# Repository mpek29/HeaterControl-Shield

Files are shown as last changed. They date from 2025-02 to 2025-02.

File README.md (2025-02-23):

# HeaterControl-Shield

## 🚀 Overview
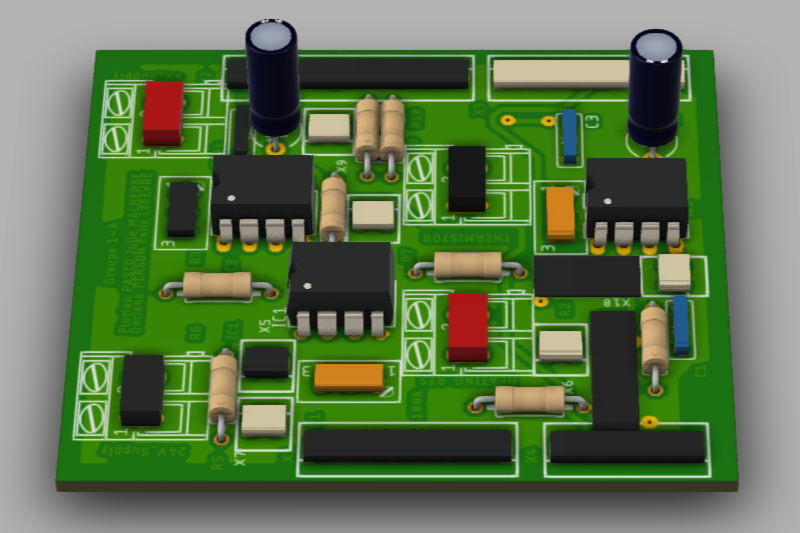
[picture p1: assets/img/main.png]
Main Preview


**HeaterControl-Shield** is an open-source electronic board designed to control a **heating resistor**, measure the **consumed current**, and detect the **temperature** near the heating resistor. This board is shaped as an **Arduino shield** and optimized for use with an **STM32 Nucleo**.

## 🎯 Main Features
- 🔥 **Heating resistor control** via an **N-channel MOSFET**.
- ⚡ **Current consumption measurement** using a **shunt resistor** and an **operational amplifier**.
- 🌡️ **Temperature sensing** using a **thermistor** integrated into a **Wheatstone bridge**, amplified by an **instrumentation amplifier**.
- 🛠️ **Open-source and customizable design** to adapt to specific project needs.

## 📝 Technical Specifications
| 🏷️ Feature | 🔍 Description |
|---|---|
| 🔌 **Power Input** | 5V - 12V |
| 🔥 **Heating Control** | N-channel MOSFET for power control |
| ⚡ **Current Measurement** | Shunt resistor + Operational amplifier |
| 🌡️ **Temperature Sensing** | Wheatstone bridge + Instrumentation amplifier |
| 🔄 **Interface** | Compatible with **Arduino Shield** and **STM32 Nucleo** |
| 🖥️ **PCB Design** | Open-source & customizable |
| 🌍 **Applications** | Thermal control projects, embedded systems, temperature regulation |

## 📐 PCB Preview
| 📜 Schematic | 🖥️ PCB Layout | 🏗️ 3D View |
|---|---|---|
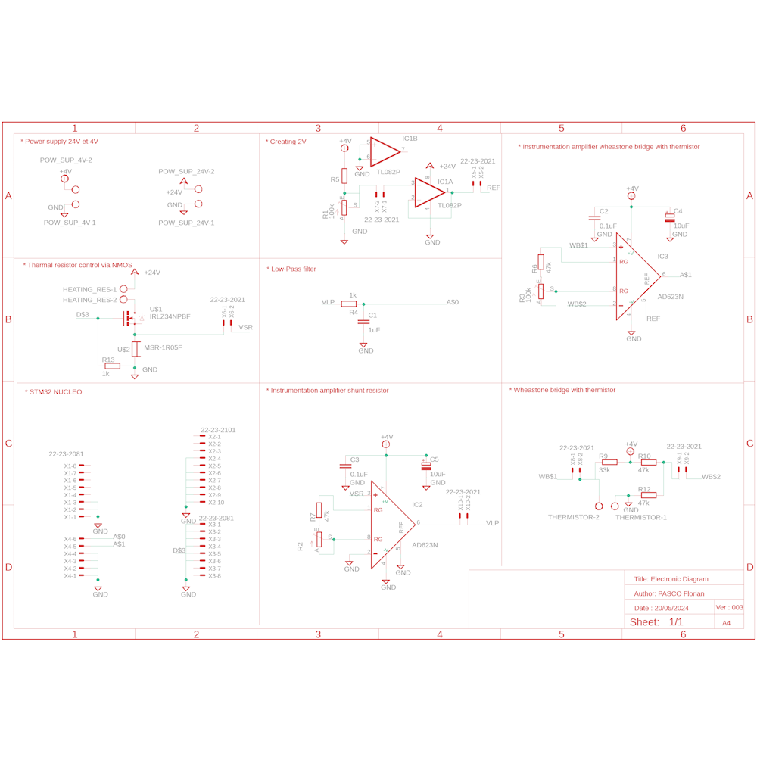
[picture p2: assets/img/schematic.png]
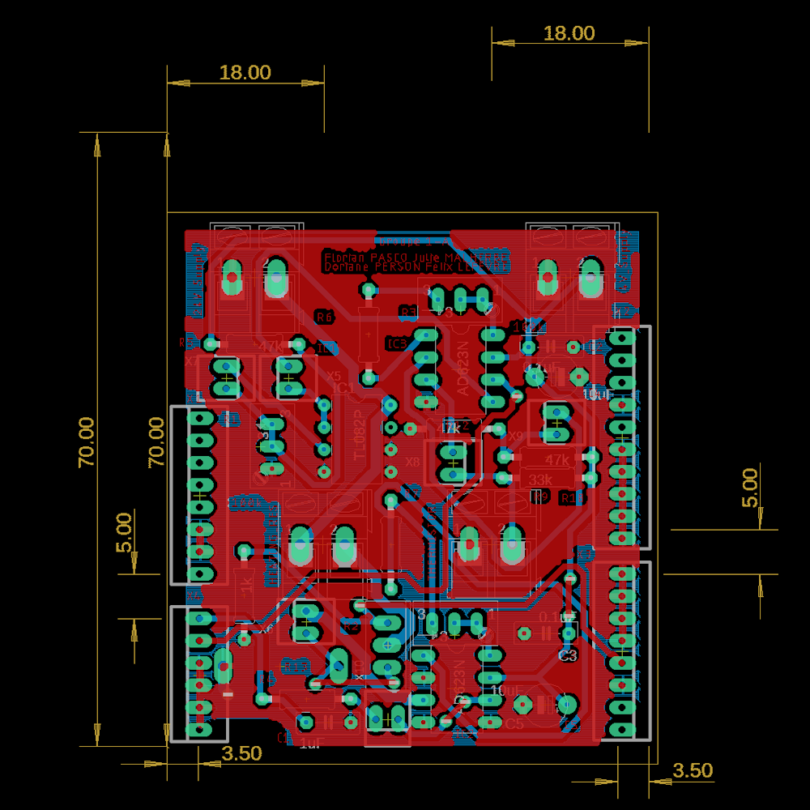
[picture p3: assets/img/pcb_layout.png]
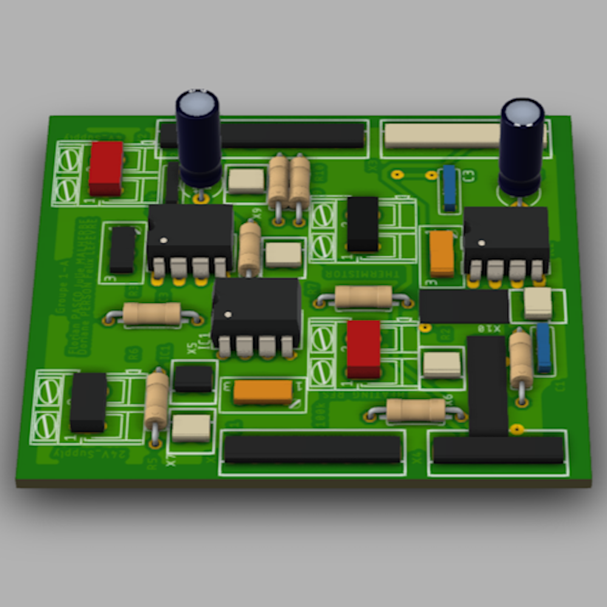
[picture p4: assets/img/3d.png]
|  |  |  |

## 🔗 Main Connections
| Pin | Function |
|-----|---|
| VIN | Main power input |
| GND | Ground |
| HEAT_CTRL | PWM signal to activate heating |
| CURR_SENSE | Amplified output of current measurement |
| TEMP_SENSE | Amplified output of temperature measurement |

## 🌟 License
This project is open-source. Feel free to use, modify, and contribute! 🚀

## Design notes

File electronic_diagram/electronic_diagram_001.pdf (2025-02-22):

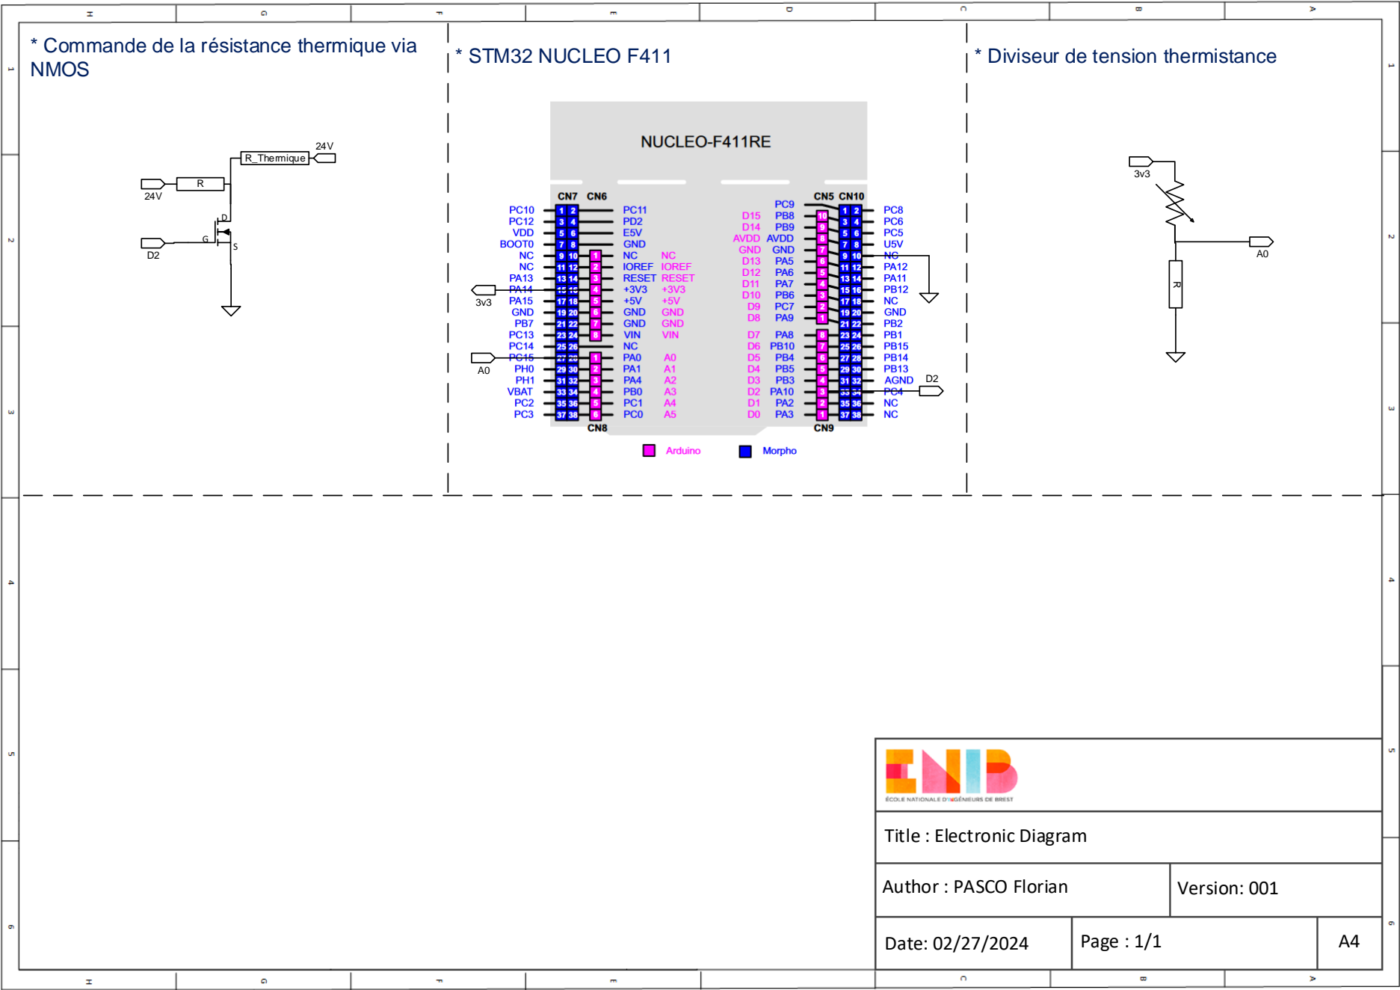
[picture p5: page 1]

Title : Electronic Diagram

Author : PASCO Florian | Version: 001
Date: 02/27/2024 | Page : 1/1 | A4

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
R_Thermique

24V

D

G
S

* Diviseur de tension thermistance * Commande de la résistance thermique via
NMOS | * STM32 NUCLEO F411

3v3

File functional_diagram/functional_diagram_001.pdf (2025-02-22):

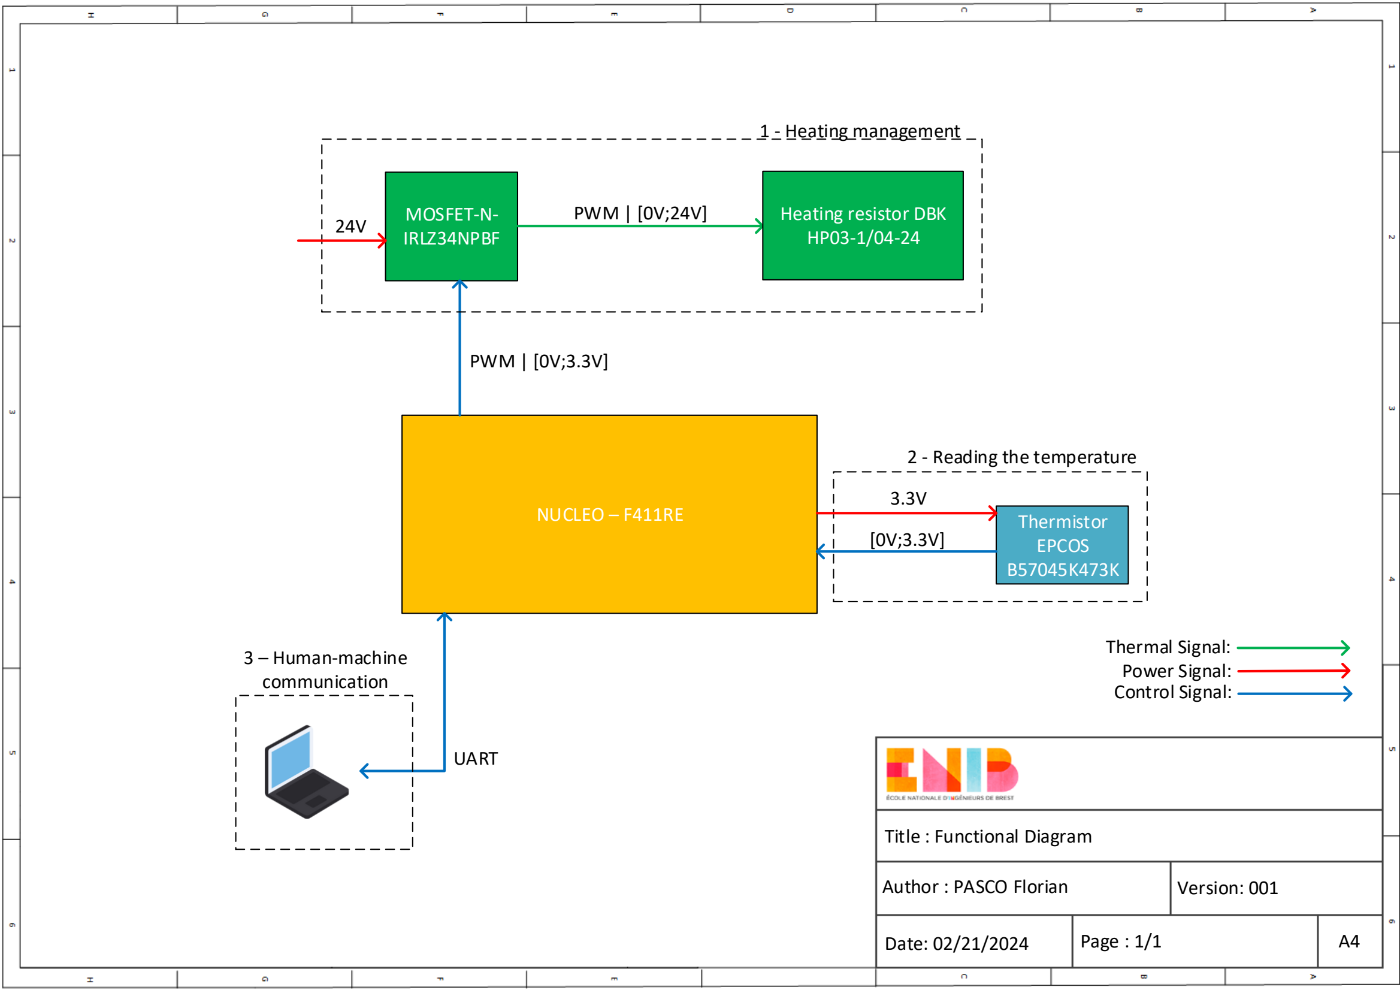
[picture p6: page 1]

NUCLEO – F411RE

MOSFET-N-IRLZ34NPBF

Thermistor
EPCOS
B57045K473K

UART

Thermal Signal:
Power Signal:
Control Signal:

1 - Heating management

2 - Reading the temperature

3 – Human-machine
communication

Heating resistor DBK
HP03-1/04-24

3.3V

[0V;3.3V]

PWM | [0V;24V]
24V
PWM | [0V;3.3V]

Title : Functional Diagram

Author : PASCO Florian | Version: 001
Date: 02/21/2024 | Page : 1/1 | A4

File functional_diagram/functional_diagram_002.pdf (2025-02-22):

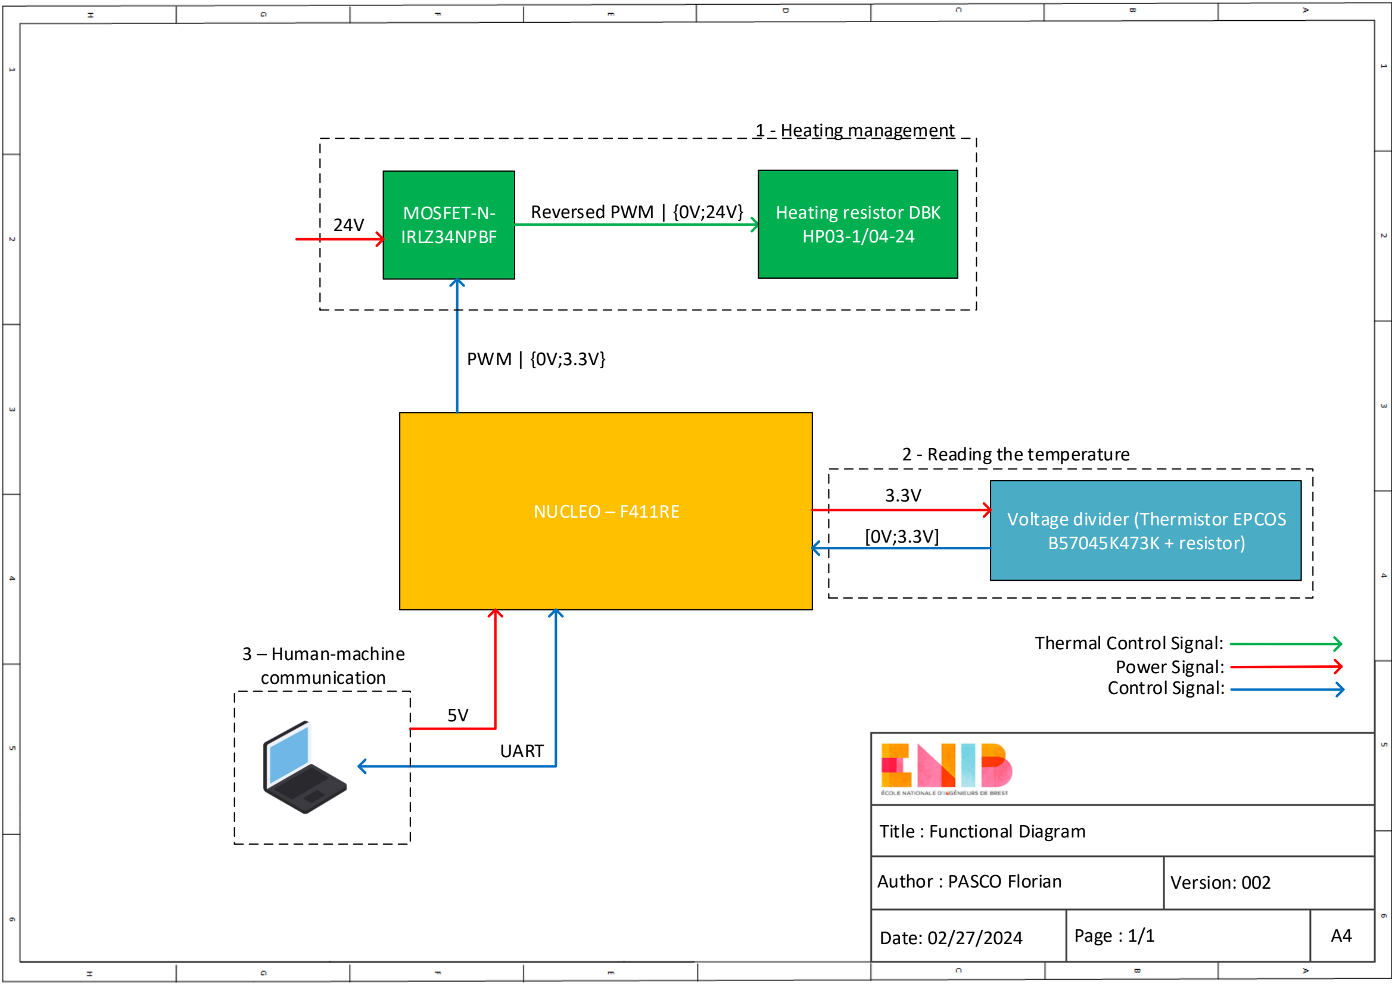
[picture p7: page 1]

NUCLEO – F411RE

MOSFET-N-IRLZ34NPBF

Voltage divider (Thermistor EPCOS B57045K473K + resistor)

UART

Thermal Control Signal:
Power Signal:
Control Signal:

1 - Heating management

2 - Reading the temperature

3 – Human-machine
communication

Heating resistor DBK
HP03-1/04-24

3.3V

[0V;3.3V]

Reversed PWM | {0V;24V}
24V
PWM | {0V;3.3V}

Title : Functional Diagram

Author : PASCO Florian | Version: 002
Date: 02/27/2024 | Page : 1/1 | A4

5V

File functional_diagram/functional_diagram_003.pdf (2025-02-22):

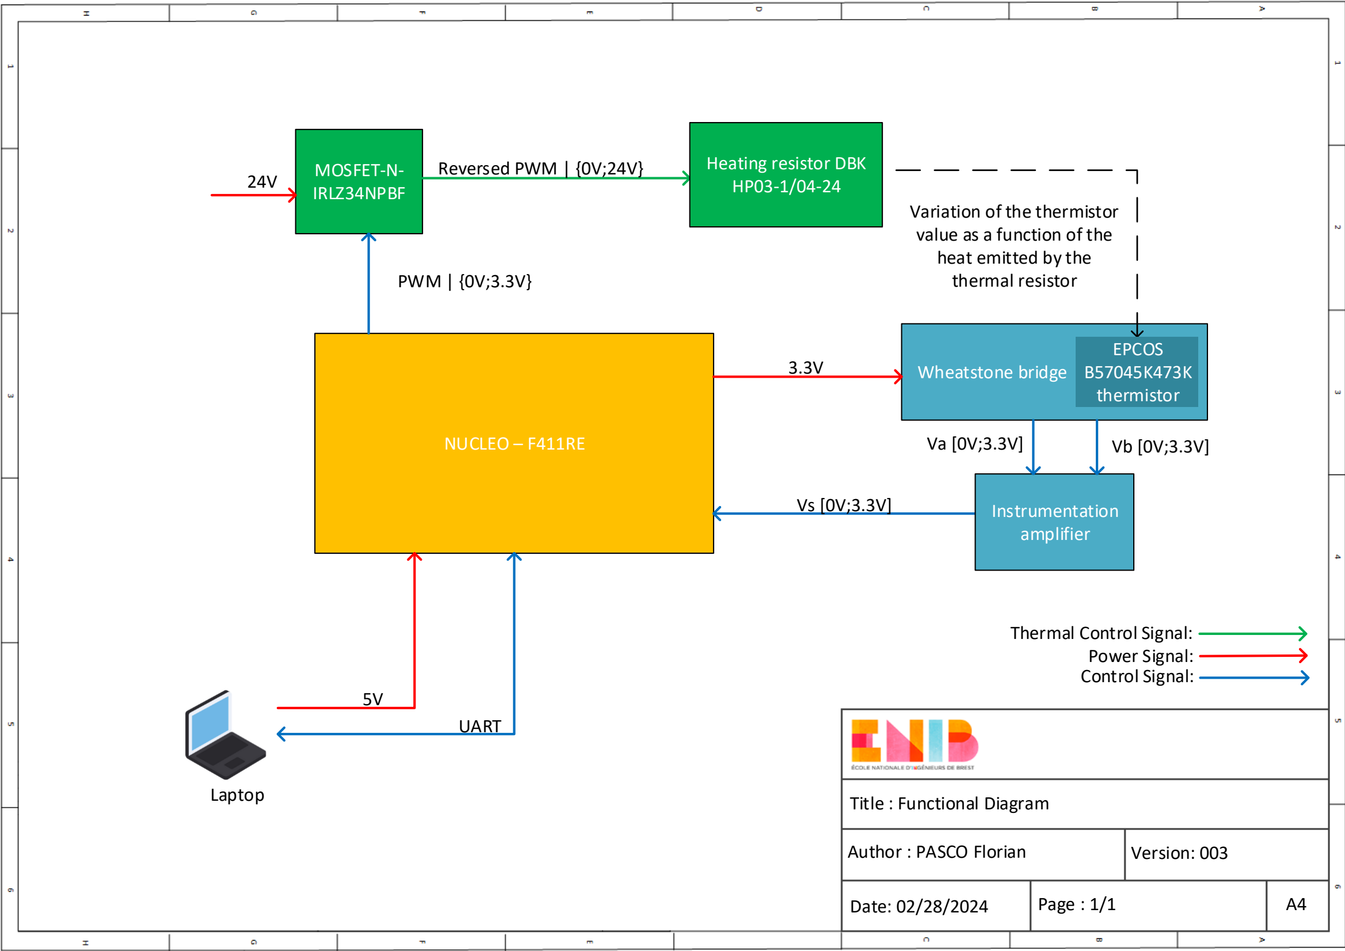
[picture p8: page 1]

NUCLEO – F411RE

MOSFET-N-IRLZ34NPBF

Wheatstone bridge

UART

Thermal Control Signal:
Power Signal:
Control Signal:

Laptop

Heating resistor DBK
HP03-1/04-24

3.3V

Vs [0V;3.3V]

Reversed PWM | {0V;24V}
24V
PWM | {0V;3.3V}

Title : Functional Diagram

Author : PASCO Florian | Version: 003
Date: 02/28/2024 | Page : 1/1 | A4

5V

Variation of the thermistor value as a function of the heat emitted by the
thermal resistor

EPCOS
B57045K473K
thermistor

Instrumentation
amplifier
Va [0V;3.3V] | Vb [0V;3.3V]

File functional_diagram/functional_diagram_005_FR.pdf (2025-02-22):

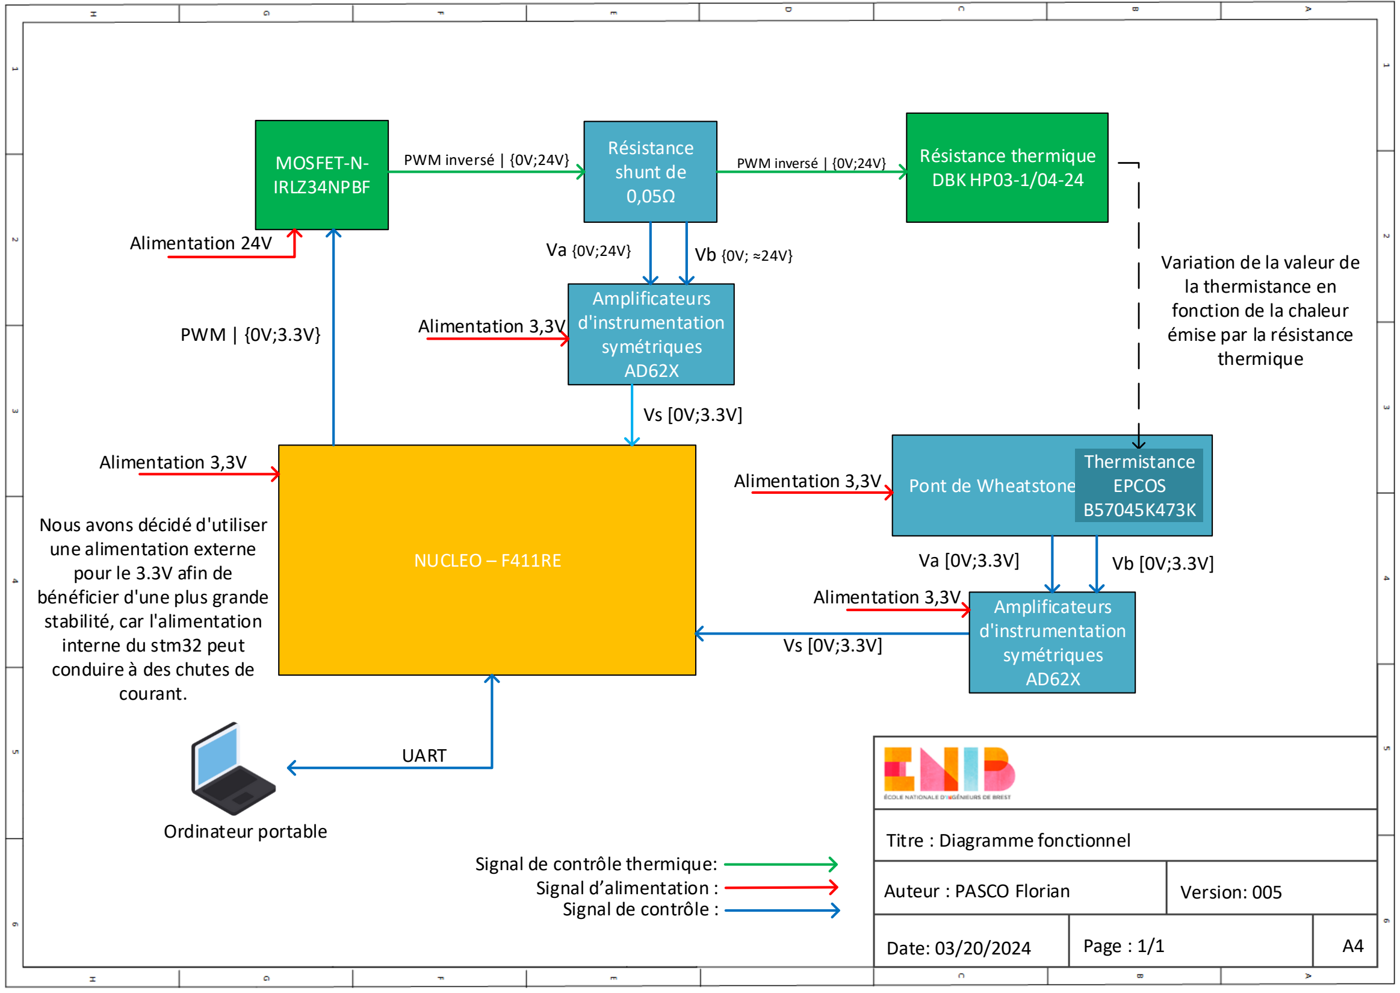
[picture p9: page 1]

NUCLEO – F411RE

MOSFET-N-IRLZ34NPBF

Pont de Wheatstone

UART

Signal de contrôle thermique: Signal d alimentation :
Signal de contrôle :

Ordinateur portable

Résistance thermique
DBK HP03-1/04-24

Alimentation 3,3V

Vs [0V;3.3V]

PWM inversé | {0V;24V}

Alimentation 24V

PWM | {0V;3.3V}

Titre : Diagramme fonctionnel

Auteur : PASCO Florian | Version: 005
Date: 03/20/2024 | Page : 1/1 | A4

Variation de la valeur de
la thermistance en
fonction de la chaleur
émise par la résistance
thermique

Thermistance
EPCOS
B57045K473K

Amplificateurs
d'instrumentation
symétriques
AD62X
Va [0V;3.3V] | Vb [0V;3.3V]

Alimentation 3,3V

Résistance
shunt de
0,05Ω

Amplificateurs
d'instrumentation
symétriques
AD62X
PWM inversé | {0V;24V}
Va {0V;24V} | Vb {0V; 24V}

Vs [0V;3.3V]

Alimentation 3,3V

Alimentation 3,3V

Nous avons décidé d'utiliser une alimentation externe
pour le 3.3V afin de
bénéficier d'une plus grande stabilité, car l'alimentation interne du stm32 peut
conduire à des chutes de
courant.

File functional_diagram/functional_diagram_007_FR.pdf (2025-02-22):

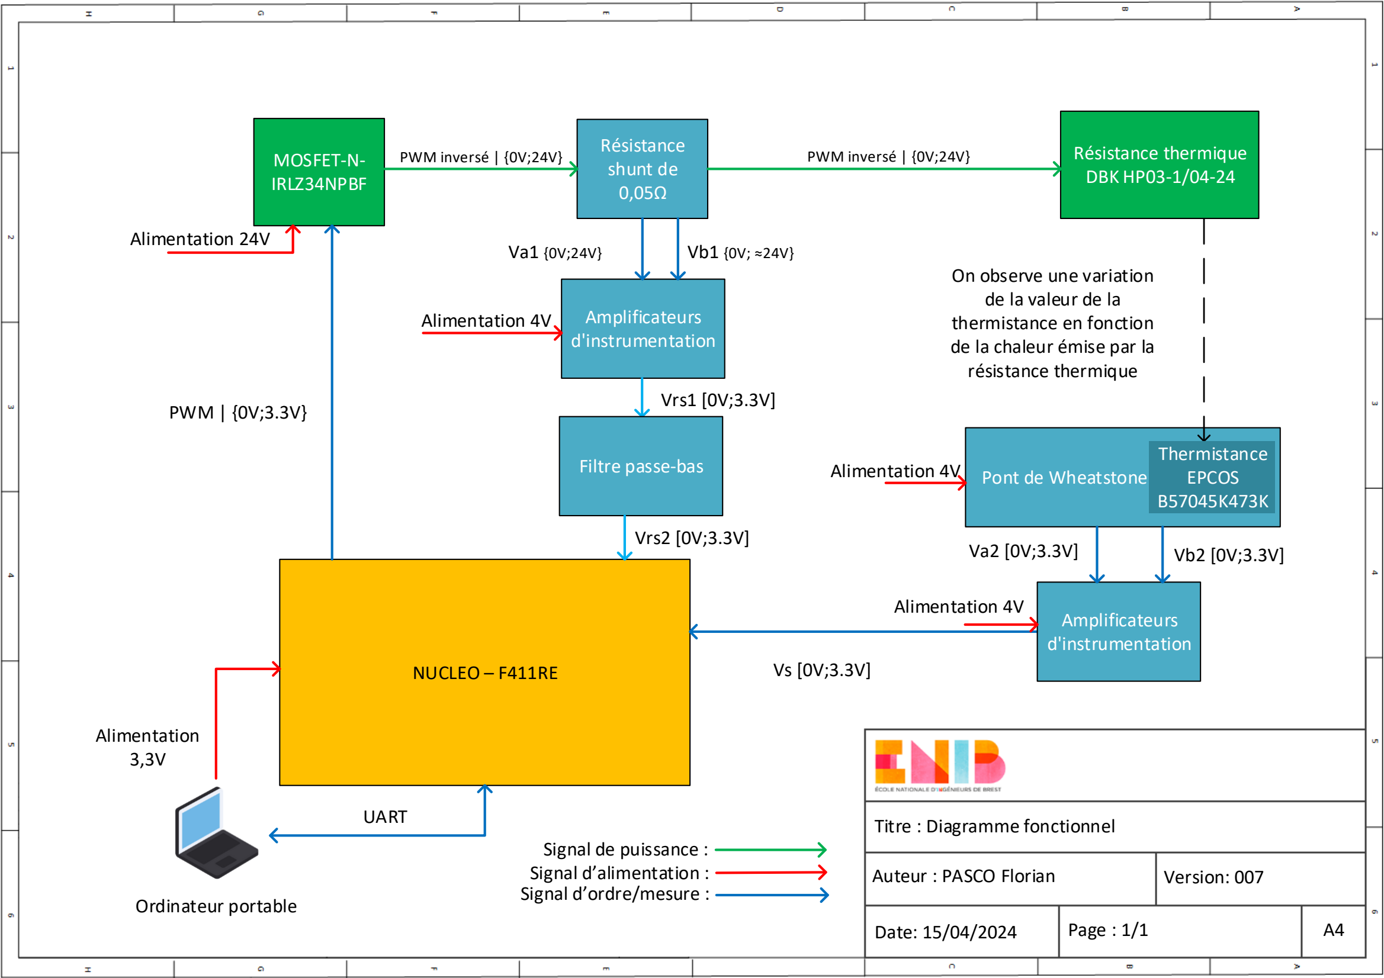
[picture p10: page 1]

NUCLEO – F411RE

MOSFET-N-IRLZ34NPBF

Pont de Wheatstone

UART
Signal de puissance :
Signal d alimentation :
Signal d ordre/mesure :
Ordinateur portable

Résistance thermique
DBK HP03-1/04-24

Alimentation 4V

Vs [0V;3.3V]

PWM inversé | {0V;24V}

Alimentation 24V

PWM | {0V;3.3V}

Titre : Diagramme fonctionnel

Auteur : PASCO Florian | Version: 007
Date: 15/04/2024 | Page : 1/1 | A4

On observe une variation
de la valeur de la
thermistance en fonction
de la chaleur émise par la résistance thermique

Thermistance
EPCOS
B57045K473K

Amplificateurs
d'instrumentation
Va2 [0V;3.3V] | Vb2 [0V;3.3V]

Alimentation 4V

Résistance
shunt de
0,05Ω

Amplificateurs
d'instrumentation
PWM inversé | {0V;24V}
Va1 {0V;24V} | Vb1 {0V; 24V}

Vrs1 [0V;3.3V]

Alimentation
3,3V

Alimentation 4V

Filtre passe-bas

Vrs2 [0V;3.3V]

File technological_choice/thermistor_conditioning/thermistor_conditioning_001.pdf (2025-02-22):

Title : Thermistor Conditioning

Author : PASCO Florian | Version: 001
Date: 02/28/2024 | Page : 1/1 | A4

3v3

A0

R

* Potentiometer mounting | * Wheatstone bridge with thermistor

+3.3V

Va | Vb

* Relaxation oscillator

Vm = Va - Vb

Advantages:
- Simple
- Inexpensive

Disadvantage:
- Not always accurate enough

Conclusion:
To be preferred whenever possible, as it's simple and inexpensive, but may not be precise enough in some cases.

Advantages:
- Possibility of adding a gain in order to have a more relevant voltage range.

Disadvantage:
- + Complex

Conclusion:
Good solution if you have analog inputs and you're not satisfied with the voltage range provided by your transducer.

Advantages:
- Very useful if you don't have a DAC, as the output signal can be analyzed by a digital input.

Disadvantage:
- Requires very precise capabilities
- Requires an external power supply for -3.3V.

Conclusion:
Very useful if your microprocessor is not equipped with a DAC.

Conclusion:
In our case, the Wheatstone bridge seems the most appropriate, since the voltage range provided by our default sensor is unsatisfactory, we have a microcontroller equipped with analog inputs, and we don't have a high-precision capacitor.

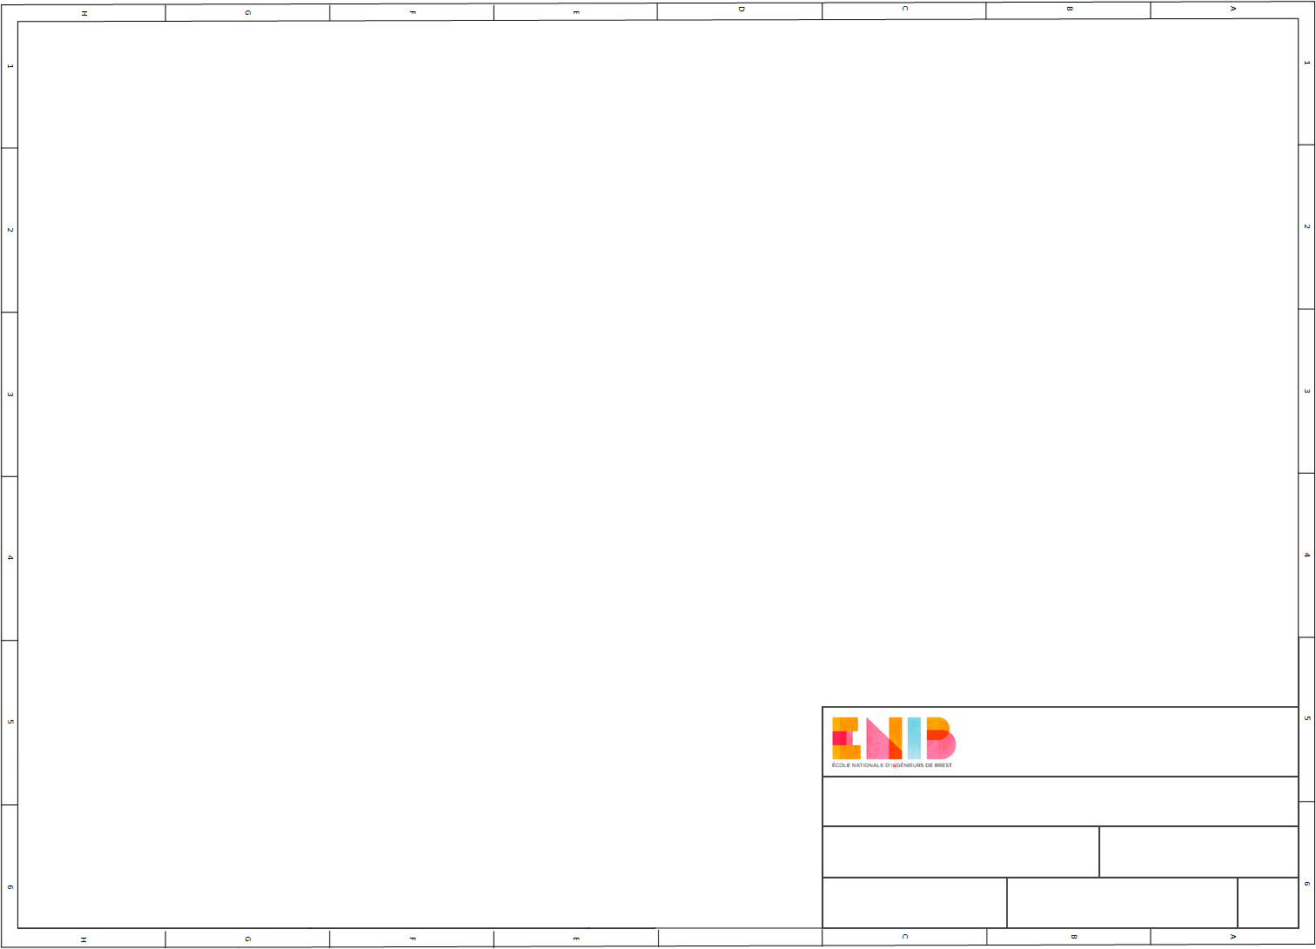
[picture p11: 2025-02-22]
bg.png

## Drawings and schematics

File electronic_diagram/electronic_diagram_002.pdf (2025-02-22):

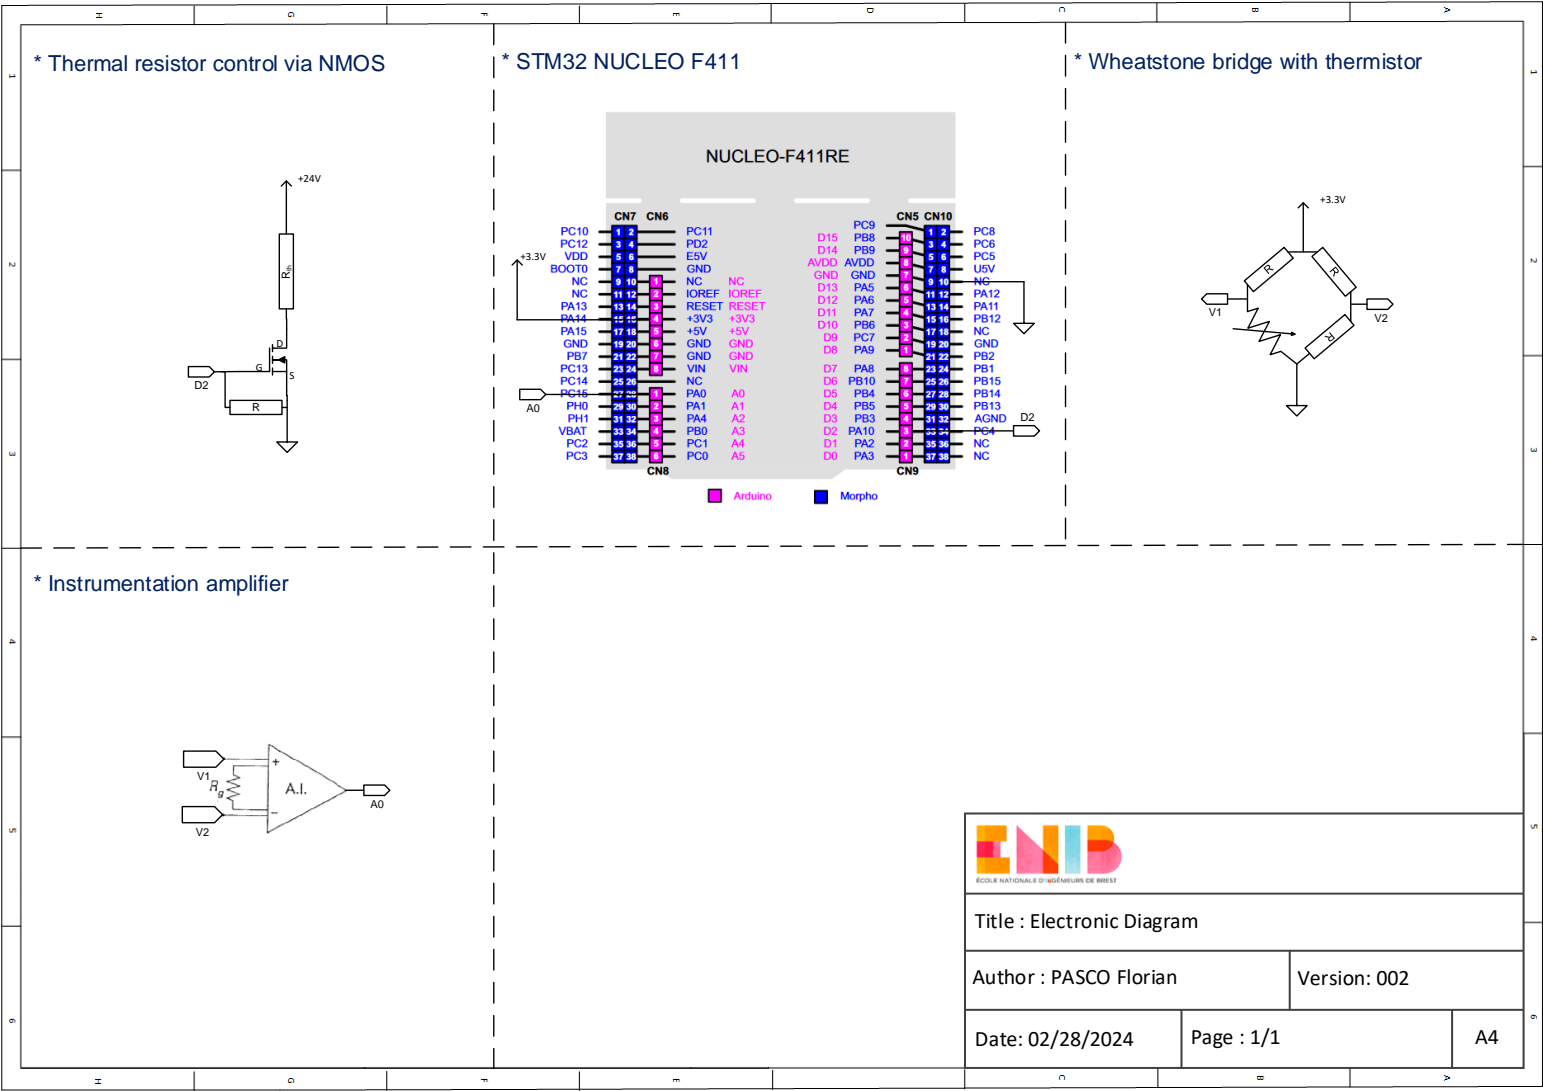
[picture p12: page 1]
Author : PASCO Florian; Version: 002; Date: 02/28/2024; Page : 1/1; Rth; * Thermal resistor control via NMOS; * STM32 NUCLEO F411; * Wheatstone bridge with thermistor; * Instrumentation amplifier

Title : Electronic Diagram

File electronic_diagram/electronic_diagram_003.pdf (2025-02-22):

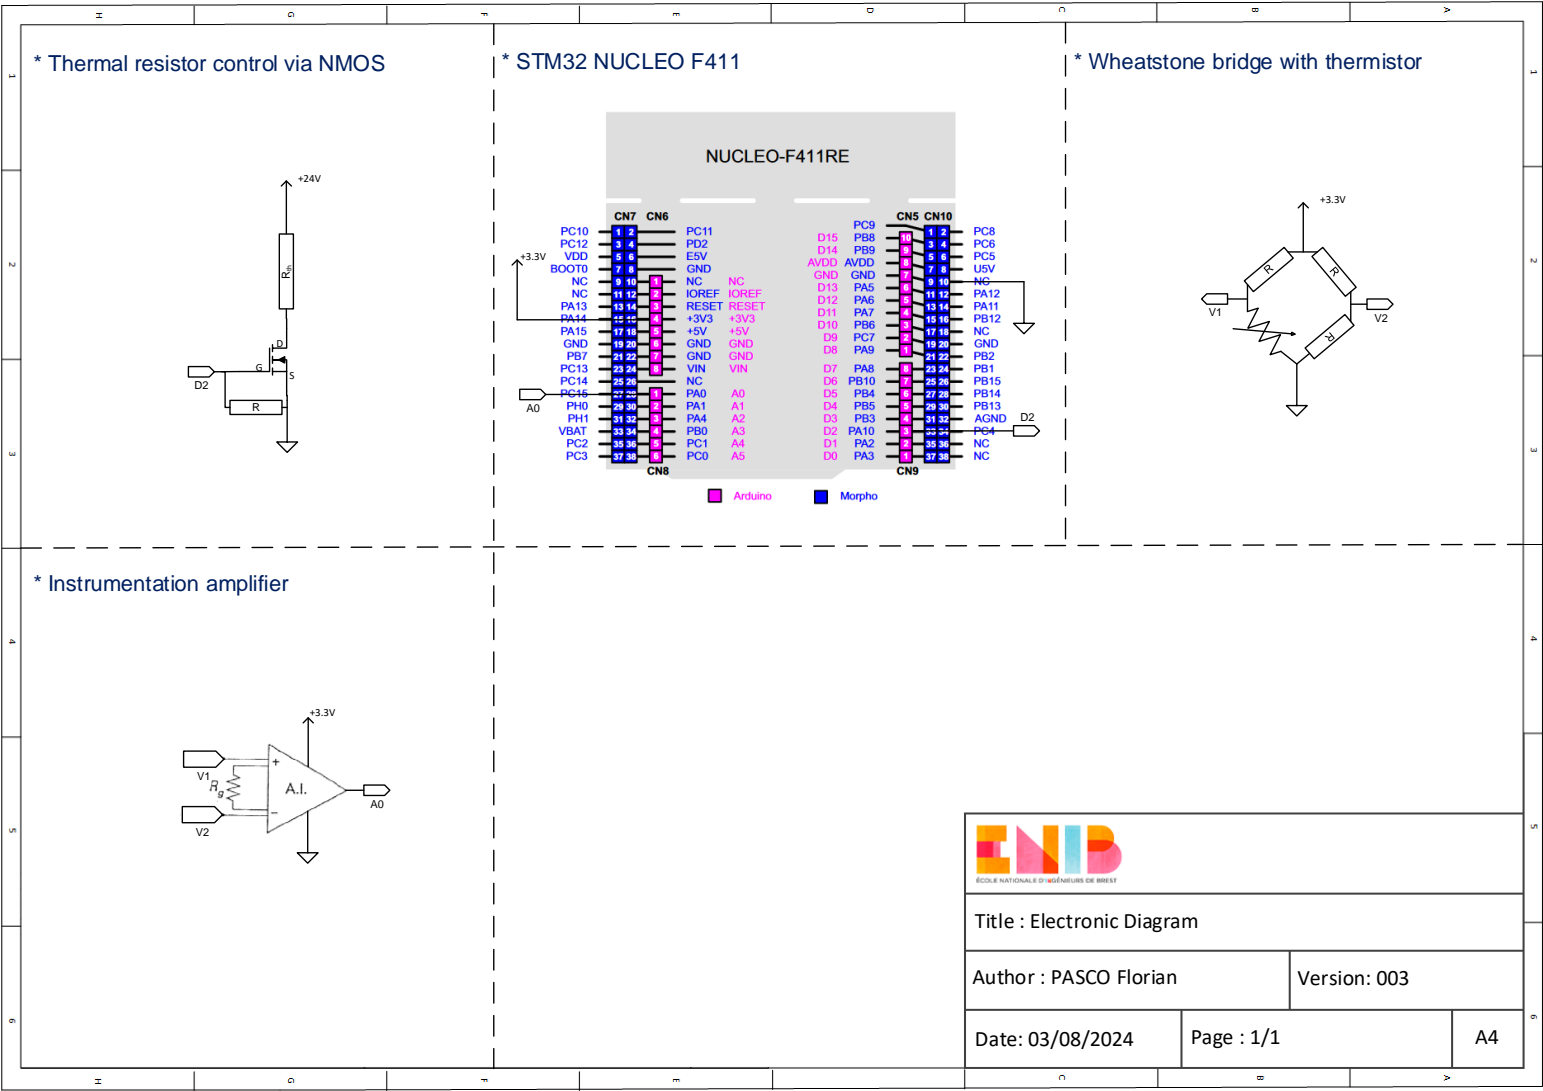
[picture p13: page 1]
Author : PASCO Florian; Version: 003; Date: 03/08/2024; Page : 1/1; Rth; * Thermal resistor control via NMOS; * STM32 NUCLEO F411; * Wheatstone bridge with thermistor; * Instrumentation amplifier

Title : Electronic Diagram

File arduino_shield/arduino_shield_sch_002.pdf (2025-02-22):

A

A

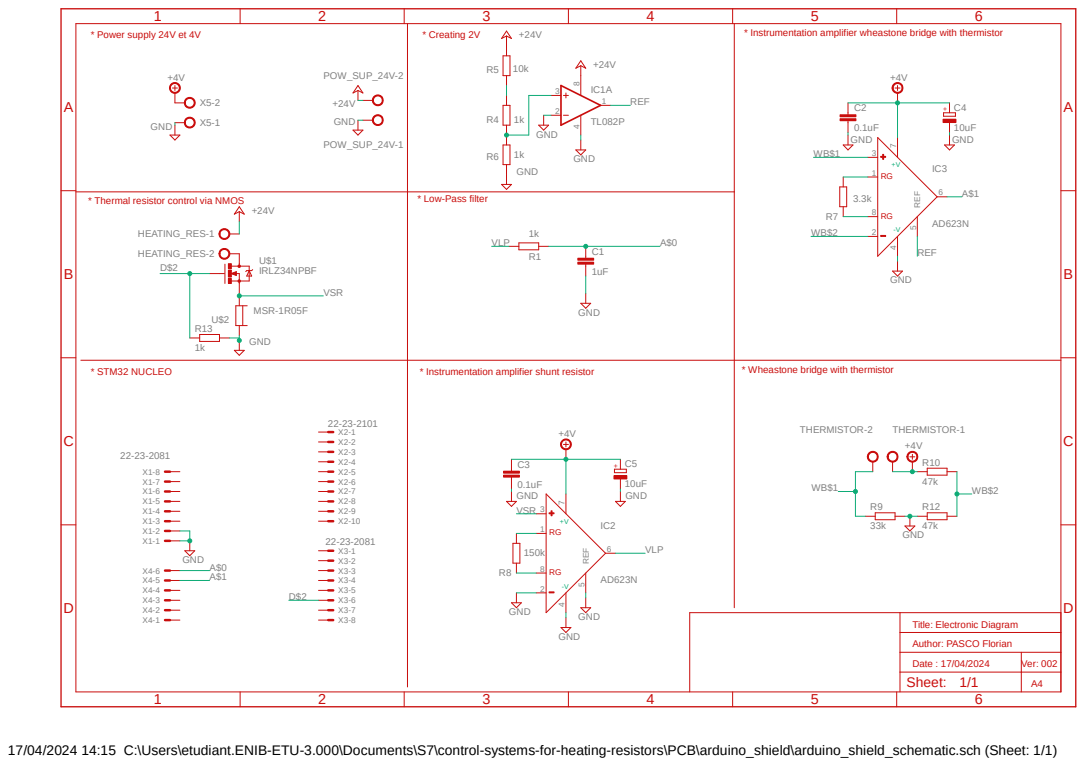
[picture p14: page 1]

+4V POW_SUP_24V-2 POW_SUP_24V-1 | | | | * Instrumentation amplifier wheastone bridge with thermistor +4V

* Thermal resistor control via NMOS

* Instrumentation amplifier shunt resistor

* Wheastone bridge with thermistor

Date : 17/04/2024 | Ver: 002
Sheet: 1/1 | A4

17/04/2024 14:15 C:\Users\etudiant.ENIB-ETU-3.000\Documents\S7\control-systems-for-heating-resistors\PCB\arduino_shield\arduino_shield_schematic.sch (Sheet: 1/1)

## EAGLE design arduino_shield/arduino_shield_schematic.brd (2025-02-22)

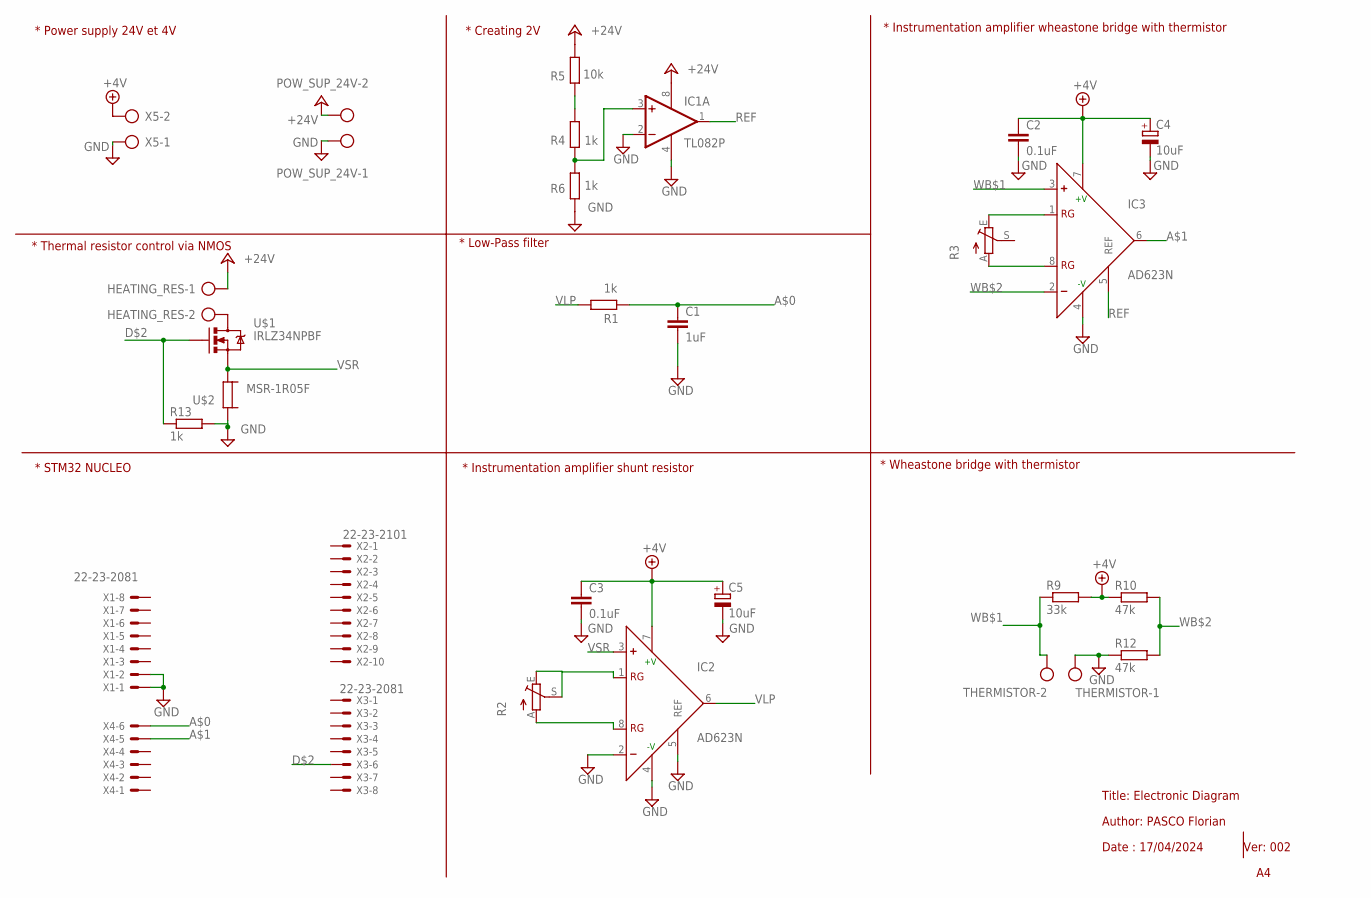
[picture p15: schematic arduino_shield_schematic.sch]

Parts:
C1: 1uF; C025-025X050
C2, C3: 0.1uF; C025-025X050
C4, C5: 10uF; E2,5-6E
HEATING_RES: AK300/2
IC1: TL082P; DIL08
IC2, IC3: AD623N; DIL08
POW_SUP_24V: AK300/2
R1, R4, R6, R13: 1k; 0207/10
R2, R3: TRIM_EU-S64W; S64W
R5: 10k; 0207/10
R9: 33k; 0207/10
R10, R12: 47k; 0207/10
THERMISTOR: AK300/2
U$1: IRLZ34NPBF; TO-220(2)
U$2: MSR-1R05F; MSR1
X1, X3: 22-23-2081
X2: 22-23-2101
X4: 22-23-2061
X5: AK300/2

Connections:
+4.1V: C2.1, C3.1, C4.+, C5.+, IC2.7 (+V), IC3.7 (+V), R9.2, R10.1, X5.2
+24V: HEATING_RES.1, IC1.8 (V+), POW_SUP_24V.2, R5.2
A$0: C1.1, R1.1, X4.6
A$1: IC3.6 (OUT), X4.5
D$2: R13.1, U$1.IN (G), X3.6
GND: C1.2, C2.2, C3.2, C4.-, C5.-, IC1.2 (-IN), IC1.4 (V-), IC2.2 (-), IC2.4 (-V), IC2.5 (REF), IC3.4 (-V), POW_SUP_24V.1, R6.1, R12.1, R13.2, THERMISTOR.1, U$2.P$2 (2), X1.1, X1.2, X5.1
unnamed: R2.E, R2.S
unnamed: R4.2, R5.1
unnamed: IC1.3 (+IN), R4.1, R6.2
unnamed: IC2.8 (RG), R2.A
unnamed: IC3.1 (RG), R3.E
unnamed: IC3.8 (RG), R3.A
unnamed: HEATING_RES.2, U$1.GND (D)
REF: IC1.1 (OUT), IC3.5 (REF)
VLP: IC2.6 (OUT), R1.2
VSR: IC2.3 (+), U$1.OUT (S), U$2.P$1 (1)
WB$1: IC3.3 (+), R9.1, THERMISTOR.2
WB$2: IC3.2 (-), R10.2, R12.2

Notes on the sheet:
Title: Electronic Diagram
Author: PASCO Florian
* STM32 NUCLEO
* Power supply 24V et 4V
* Creating 2V
* Thermal resistor control via NMOS
* Instrumentation amplifier shunt resistor
* Instrumentation amplifier wheastone bridge with thermistor
* Wheastone bridge with thermistor
* Low-Pass filter
Ver: 002
Date : 17/04/2024

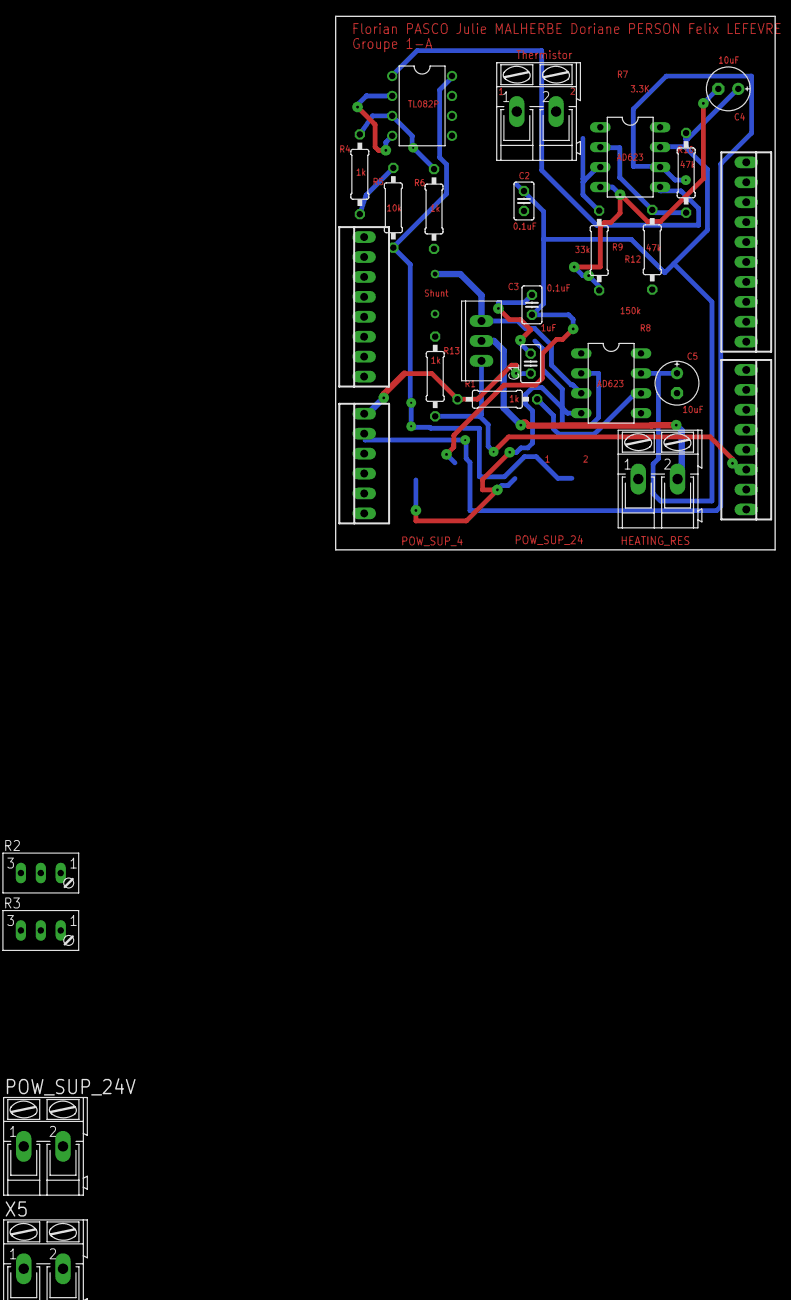
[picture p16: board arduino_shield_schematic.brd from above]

Board: 2 copper layers, 56.0 x 68.0 mm, 28 parts (0 on the bottom side), 18 nets.

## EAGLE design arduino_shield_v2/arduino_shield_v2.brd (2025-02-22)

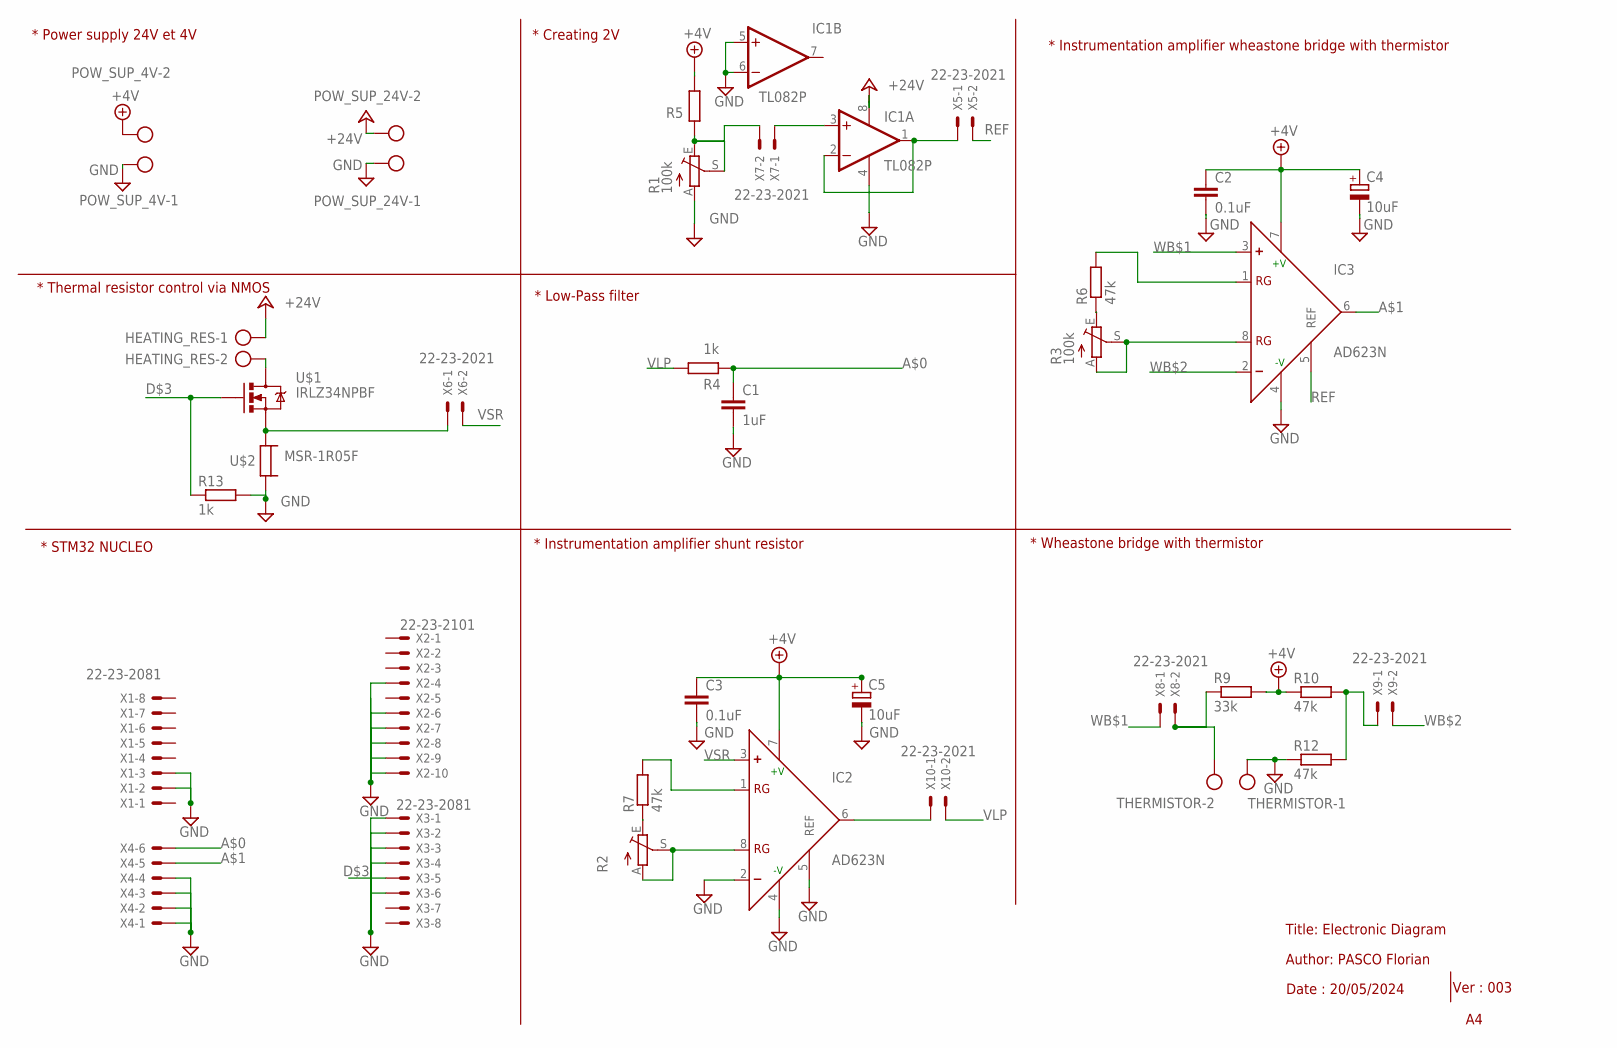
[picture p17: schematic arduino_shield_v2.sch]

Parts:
C1: 1uF; C050-025X075
C2, C3: 0.1uF; C050-025X075
C4, C5: 10uF; E5-5
HEATING_RES: AK300/2
IC1: TL082P; DIL08
IC2, IC3: AD623N; DIL08
POW_SUP_4V, POW_SUP_24V: AK300/2
R1, R3: 100k; S64W
R2: TRIM_EU-S64W; S64W
R4, R13: 1k; 0207/10
R5, R6, R7, R10, R12: 47k; 0207/10
R9: 33k; 0207/10
THERMISTOR: AK300/2
U$1: IRLZ34NPBF; TO-220(2)
U$2: MSR-1R05F; MSR1
X1, X3: 22-23-2081
X2: 22-23-2101
X4: 22-23-2061
X5, X6, X7, X8, X9, X10: 22-23-2021

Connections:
+4.1V: C2.1, C3.1, C4.+, C5.+, IC2.7 (+V), IC3.7 (+V), POW_SUP_4V.2, R5.2, R9.2, R10.1
+24V: HEATING_RES.1, IC1.8 (V+), POW_SUP_24V.2
A$0: C1.1, R4.1, X4.6
A$1: IC3.6 (OUT), X4.5
D$3: R13.1, U$1.IN (G), X3.5
GND: C1.2, C2.2, C3.2, C4.-, C5.-, IC1.4 (V-), IC1.5 (+IN), IC1.6 (-IN), IC2.2 (-), IC2.4 (-V), IC2.5 (REF), IC3.4 (-V), POW_SUP_4V.1, POW_SUP_24V.1, R1.A, R12.1, R13.2, THERMISTOR.1, U$2.P$2 (2), X1.2, X1.3, X2.4, X2.6, X2.7, X2.8, X2.9, X2.10, X3.1, X3.2, X3.3, X3.4, X3.6, X4.1, X4.2, X4.3, X4.4
unnamed: R1.E, R1.S, R5.1, X7.2
unnamed: R2.E, R7.1
unnamed: IC3.1 (RG), R6.2
unnamed: IC3.8 (RG), R3.A, R3.S
unnamed: IC2.8 (RG), R2.A, R2.S
unnamed: R3.E, R6.1
unnamed: IC2.1 (RG), R7.2
unnamed: IC1.3 (+IN), X7.1
unnamed: IC2.6 (OUT), X10.1
unnamed: HEATING_RES.2, U$1.GND (D)
unnamed: R10.2, R12.2, X9.1
unnamed: R9.1, THERMISTOR.2, X8.2
unnamed: IC1.1 (OUT), IC1.2 (-IN), X5.1
unnamed: U$1.OUT (S), U$2.P$1 (1), X6.1
REF: IC3.5 (REF), X5.2
VLP: R4.2, X10.2
VSR: IC2.3 (+), X6.2
WB$1: IC3.3 (+), X8.1
WB$2: IC3.2 (-), X9.2

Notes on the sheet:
Title: Electronic Diagram
Author: PASCO Florian
* STM32 NUCLEO
Date : 20/05/2024
Ver : 003
* Instrumentation amplifier wheastone bridge with thermistor
* Creating 2V
* Power supply 24V et 4V
* Wheastone bridge with thermistor
* Thermal resistor control via NMOS
* Instrumentation amplifier shunt resistor
* Low-Pass filter

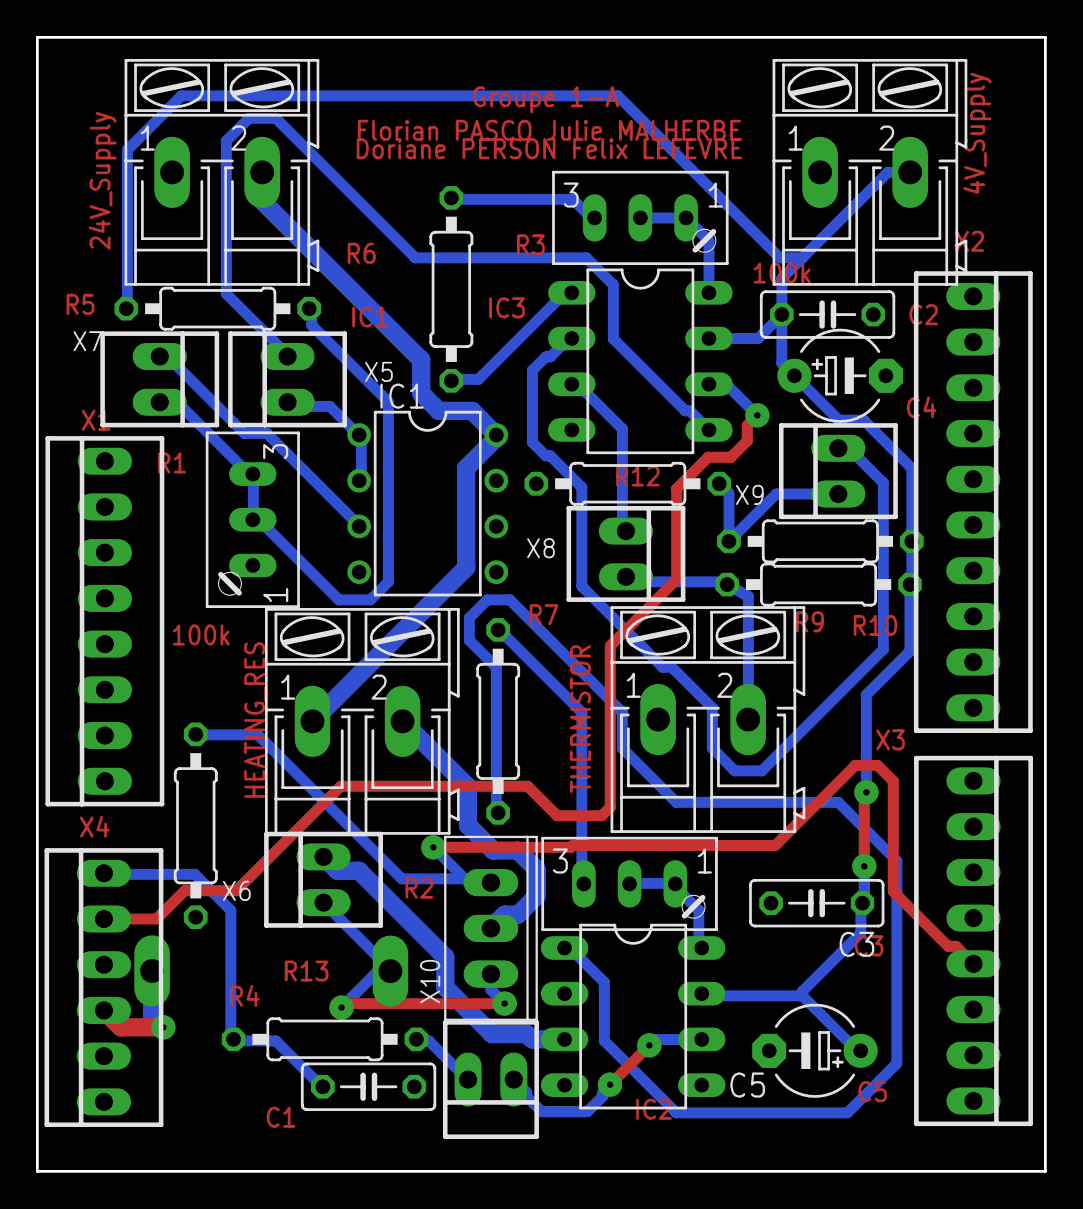
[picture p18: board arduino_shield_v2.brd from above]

Board: 2 copper layers, 56.0 x 63.0 mm, 35 parts (0 on the bottom side), 25 nets.
